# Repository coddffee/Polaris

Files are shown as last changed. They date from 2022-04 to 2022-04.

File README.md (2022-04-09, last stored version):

# `K210`工程配置

## 编译环境

### `Windows`平台

```xxx
1.配置GCC编译环境 : 下载MinGW-64并将根目录下的bin路径添加至系统环境变量，使用"gcc --version"命令检查是否配置成功
2.配置RISCV编译工具链 : 在K210官网下载kendryte-toolchain-win-amd64工具链并将根目录下的bin路径添加至系统环境变量，
  使用"riscv64-unknown-elf-gcc --version"命令检查是否配置成功
3.配置CMake : 下载CMake并将根目录下的bin路径添加至系统环境变量，使用"cmake --version"检查是否配置成功
```

### `Linux`平台

```xxx
TODO
```

## 工程结构

### K210-Standalone-SDK文件结构

```xxx
K210-Standalone-SDK
|---cmake
    |---CMakeLists.txt
    |---common.cmake
    |---compile-flags.cmake
    |---dump-config.cmake
    |---executable.cmake
    |---fix-9985.cmake
    |---macros.cmake
    |---macros.internal.cmake
    |---toolchain.cmake
|---lib
    |---bsp
        |---include
            |---xxx.h
        |---crt.S
        |---xxx.c
    |---drivers
        |---include
            |---xxx.h
        |---xxx.c
    |---utils
        |---include 
            |---syslog.h
    |---CMakeLists.txt
|---lds(链接脚本)
    |---kendryte.ld
```

&emsp;&emsp;使用`CMakeLists.txt`配置工程时需要直接使用`SDK`下`cmake`中的`CMakeLists.txt`,`common.cmake`和`executable.cmake`，`cmake`文件夹中的文件作用分别为：

```xxx
1.CMakeLists.txt : 配置SDK工程结构，生成名为kendryte的静态链接库
2.macros.cmake&macros.internal.cmake : 定义一些工具函数和变量
3.toolchain.cmake : 用于配置编译工具链，要求提前定义WIN32变量用于指定编译平台，
  要求提前定义TOOLCHAIN变量用于指定编译工具链所在目录(工具链根目录下的bin路径)
4.compile-flags.cmake : 存放编译和链接选项
5.dump-config.cmake : 用于打印一些必要变量的值辅助检查工程的配置
6.fix-9985.cmake : 进行某些字符串的替换
7.common.cmake : 调用toolchain.cmake,compile-flags.cmake和fix-9985.cmake,主要用于配置编译工具链，设置编译链接选项，
  此文件应该在所有生成目标文件的指令之前调用，可在项目级CMakeLists.txt的靠前部分调用
8.executable.cmake : 用于生成可执行文件，此文件要求提前定义变量SOURCE_FILES用于存储生成可执行文件的源文件，
  并指定可执行文件的文件名为${PROJECT_NAME},此文件应该在工程的链接操作之前调用，另外此文件还进行了可执行文件格式转换操作，
  将GCC编译器编译得到的ELF格式文件转换为二进制格式文件
```

## 工程配置

### 工程级`CMakeLists.txt`编写

```cmake
# 开启交叉编译
set(CMAKE_SYSTEM_NAME Generic)
cmake_minimum_required(VERSION 3.0)
project(Polaris LANGUAGES C ASM)

# SDK配置
# 设置编译工具链路径，TOOLCHAIN是K210-SDK中定义的变量，需由使用者指定
set(TOOLCHAIN C:/DevEnv/Kendryte-Toolchain/bin)
# 指定编译平台为WIN32，WIN32是K210-SDK中定义的变量，根据此变量指定toolchain的后缀名，需由使用者指定
set(WIN32 TRUE)

add_subdirectory(${PROJECT_SOURCE_DIR}/sdk/k210/cmake)
```

### 项目编译

&emsp;&emsp;`Windows`平台：

```shell
# 在build目录下运行cmake指令，产生的Makefiles将存放于build目录下，避免污染项目结构
cd ./build
# 运行cmake指令时必须使用"-G"指定cmake生成器，否则无法进行交叉编译
# 对于Windows平台使用MinGW-GCC环境，cmake生成器为"MinGW Makefiles"
cmake -G "MinGW Makefiles" ../
# 运行make指令执行Makefiles完成编译
make
```

&emsp;&emsp;`Linux`平台：

```shell
# 在build目录下运行cmake指令，产生的Makefiles将存放于build目录下，避免污染项目结构
cd ./build
# 运行cmake指令时必须使用"-G"指定cmake生成器，否则无法进行交叉编译
# 对于Linux平台，cmake生成器为"Unix Makefiles"
cmake -G "Unix Makefiles" ../
# 运行make指令执行Makefiles完成编译
make
```

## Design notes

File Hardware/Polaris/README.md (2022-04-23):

# 硬件设计

## K210

&emsp;&emsp;[官方数据手册](https://github.com/kendryte/kendryte-doc-datasheet)

### 电源

&emsp;&emsp;K210的电源引脚：

| 电源PIN组 | 电压 | 功能 | 最大电流 |
| :---: | :---: | :---: | :---: |
| VDDIOxA(x=0~2) | 1.8V/3.3V | 为可切换电压的GPIO-GroupA/Bankx(x=0~2)供电 |  200mA |
| VDDIOxB(x=3~5) | 1.8V/3.3V | 为可切换电压的GPIO-GroupB/Bankx(x=3~5)供电 |  200mA |
| VDDIOxB(x=6~7) | 1.8V/3.3V | 为可切换电压的GPIO-GroupC/Bankx(x=6~7)供电 |  200mA |
| VDDIO18 | 1.8V | 为不可切换电压(固定为1.8V)的专用功能IO供电 |  200mA |
| VDDOTP | 1.8V | 为一次可编程存储器供电 | 50mA |
| VDD | 0.9V | 为K210核心供电 |  2000mA  |
| VSS | 0V | 数字接地 | --- |
| VDDPLL | 0.9V | 锁相环电路供电 | 15mA |
| VSSPLL | 0V | 锁相环电路接地，噪声敏感 | --- |

&emsp;&emsp;K210的48个GPIO按照电源可分为3组，分别是VDDIOxA,VDDIOxB,VDDIOxC, A,B,C三组又可分为8个Bank，分别为Bank0~Bank7,分别对应的GPIO为：

| Bank | Bank | GPIO |
| :--: | :--: | :---: |
|  0 |  A |  IO-0~IO_5  |
|  1 |  A | IO-6~IO_11  |
|  2 |  A | IO-12~IO_17 |
|  3 |  B | IO-18~IO_23 |
|  4 |  B | IO-24~IO_29 |
|  5 |  B | IO-30~IO_35 |
|  6 |  C | IO-36~IO_41 |
|  7 |  C | IO-42~IO_47 |

&emsp;&emsp;VDDIO18供电的IO均为专用IO,功能固定，分别是：

| IO | 功能 |
| :---: | :---: |
| SPIO_D0~SPIO_D7 | SPIO0专用IO |
| DVP_D0~DVP_D7 | DVP专用IO |
| F_CLK,F_CS,F_D0,F_D1,F_D2,F_D3 | SPI-FLASH专用IO |
| RESET,CLK,OSC_CLK,XTAL_IN,XTAL_OUT | 复位，有源&无源时钟输入输出 |

&emsp;&emsp;使得K210正常工作必须提供3.3V,1.8V,0.9V这三个电源，除PLL外其余电源均可直接接入VSS数字电源地，至于PLL电源可分别将VDDPLL与VSSPLL串联合适的磁珠或0ohm电阻接入数字电源0.9V和VSS.可选用三通道的电源管理芯片。

### 时钟

&emsp;&emsp;K210的时钟引脚：

| 引脚 | 功能 | 说明 |
| :---: | :---: | :---: |
| XTAL_IN(M4)  |  无源晶振输入  | 禁止灌入有源信号 |
| XTAL_OUT(M3) |  无源晶振输出  | 禁止灌入有源信号 |
| OSC_CLK(L3)  | 有源振荡器输出 | 时钟源自外部无源晶振 |
| CLK(M2) |  系统时钟输入  | 输入有源信号 |

&emsp;&emsp;可直接向CLK输入有源信号为系统提供时钟，也可接入26MHz无源晶振，再将OSC_CLK输出的信号输入CLK为系统提供时钟。具体选用SMD-3225四脚封装形式的26MHz无源晶振。

### BOOT

&emsp;&emsp;B12(IO_16)是K210的启动模式选择引脚(BOOT)，上电复位时IO_16为高则从FLASH启动，IO_16为低则进入ISP模式；ISP模式下使用H11(IO_4,UART0_RX)和H12(IO_5,UART0_TX)引脚通过UART下载程序到FLASH.复位引脚为M1(RESETN,IO-1.8V),低电平复位。<br>&emsp;&emsp;项目中将BOOT,RESET,UART_RX,UART_TX四个用于程序下载的引脚以触点形式引出，并与充电接口一同封装，ISP下载程序时由外部与触点连接的连接器拉低BOOT,RESET信号也由外部给出。另外正常模式下UART_RX与UART_TX可作为外部扩展模块的通信接口。

### FLASH

&emsp;&emsp;K210不具备片上FLASH,需要通过专用SPI3连接至外部FLASH,引脚如下：

| 引脚 | 功能  | 说明 |
| :---: | :---: | :---: |
| F_D0(J1)  |  DI | Data Input, 1.8V only |
| F_D1(G1)  |  DO | Data Output, 1.8V only |
| F_D2(H1)  |  /WP  | Write Protect Input, 1.8V only |
| F_D3(L1)  | /Hold | Hold Input, 1.8V only |
| F_CLK(K1) |  CLK  | SPI Clock, 1.8V only |
| F_CS(G2)  |  /CS  | SPI Chip Select, 1.8V only |

&emsp;&emsp;SPI-FLASH芯片必须使用1.8V芯片，可选择容量为SPI-NOR-FLASH类型的8MiB(8.192MB)/16MiB(16.384MB)/32MiB(32.768MB).通信协议使用QSPI(Queued-SPI,6wire).<br>&emsp;&emsp;SPI-FLASH具体型号选用GD25LQ128DWIGR(兆易创新)，1.8V驱动电压，128M-bit存储容量，WSON8(6mm*5mm)封装。

## 系统电源

### K210

&emsp;&emsp;必须为K210提供0.9V,1.8V和3.3V三种规格的电压，推荐使用三通道单片机专用电源管理芯片RY1303. RY1303具有三路Buck转换器，输入电压范围为2.7V-5.5V, 输出电压可调范围为0.6V-Vin. 最大连续负载电流为2A, 三通道功率总和必须小于6W. 需注意RY1303与RY1303A有所区别，RY1303的16脚为VCC, RY1303A的16脚为NC.

### 电池管理

&emsp;&emsp;使用3.7V锂聚合物电池为系统供电，电池管理电路包含电池保护电路、充电管理电路和电量计电路三部分，保护电路用于避免电池的过充、过放；充电管理电路用于为电池充电并将电池电压升压后提供系统使用，电量计用于上报电池电量百分比。

### 其他外设

## 显示屏

&emsp;&emsp;显示屏使用上海冠显TA018NHV01-1.78寸AMOLED屏幕，其分辨率为368*448(24位RGB), 显示驱动为RM69090, 可选择MIPI接口或SPI接口与之通信；触摸驱动为TMA525C, 使用I2C接口与之通信。

## 传感器

&emsp;&emsp;重力加速度传感器使用MPU6500, 其驱动电压范围为1.8V-3.3V; 通过SPI总线和中断线与K210通信；电子指南针传感器使用HMC5883L, 其驱动电压范围为2.6V-3.3V; 通过I2C总线与中断线与K210通信。

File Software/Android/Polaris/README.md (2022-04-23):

# 高德地图API使用笔记

## 获取API-Key

&emsp;&emsp;API-Key是使用高德地图API时必须使用的密钥，可在高德地图开发者控制台上通过创建一个新应用的方式获取API-Key, 一个Key只能用于一个应用的开发。创建应用之前需要在AndroidStudio中获取发布版安全码SHA1和调试版安全码SHA1及应用Package.

### 获取SHA1

```xxx
1.将JDK自带的keytool添加至环境变量(将JDK安装目录下的bin路径添加至环境变量即可)
2.在AndroidStudio下创建keystore:
  (1)依次点击Build->Generate Signed Bundle / APK
  (2)选择存储路径并输入keystore名和密码
  (3)选择keystore的应用目标(debug/release或者两者均是)
3.获取SHA1:
  (1)打开终端并切换到步骤2生成的keystore所在的目录下
  (2)输入命令"keytool -list -v -keystore xxx.jks","xxx.jks"为keystore文件名，新版AndroidStudio的keystore后缀为.jks
  (3)输入步骤2中生成keystore时设置的密码
  (4)在返回信息中可查看SHA1
```

### 获取Package

&emsp;&emsp;即App的`AndroidManifest.xml`中的根标签的package属性。

### 创建高德地图新应用

&emsp;&emsp;在高德地图开发者控制台的应用管理中创建新应用并输入SHA1和Package即可得到对应的API-Key

### 在开发中使用API-Key

&emsp;&emsp;在`AndroidManifest.xml`的`<application>`标签中添加API-Key, 如：

```xml
<application...>
    <!-- value属性赋API-Key -->
    <meta-data
        android:name="com.amap.api.v2.apikey"
        android:value="45ebf..."/>
    ...
</application...>
```

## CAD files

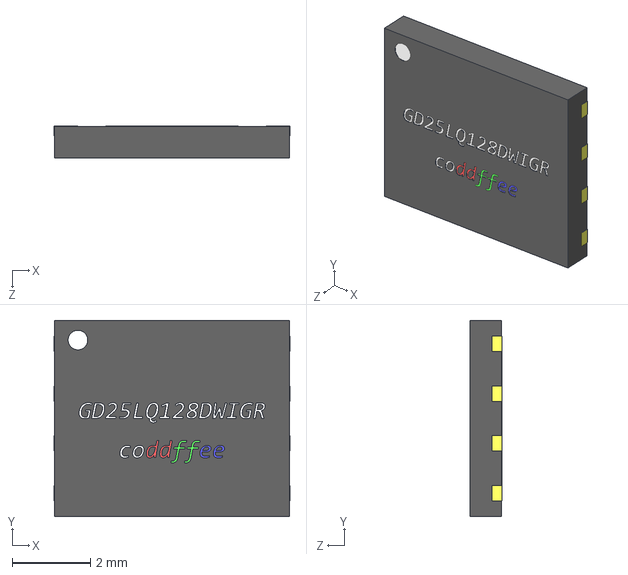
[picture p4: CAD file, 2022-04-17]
Mechanic/PCB3DLib/GD25LQ128DWIGR/GD25LQ128DWIGR.STEP
6.02 x 5.00 x 0.81 mm

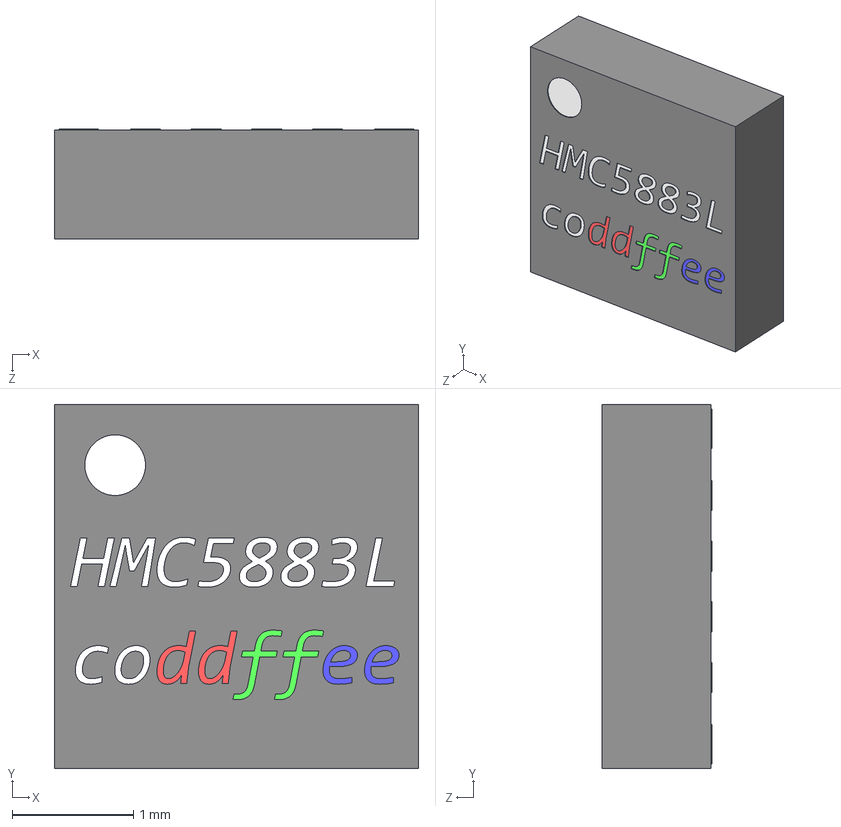
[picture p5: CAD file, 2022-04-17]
Mechanic/PCB3DLib/HMC5883L/HMC5883L.STEP
3.00 x 3.00 x 0.91 mm

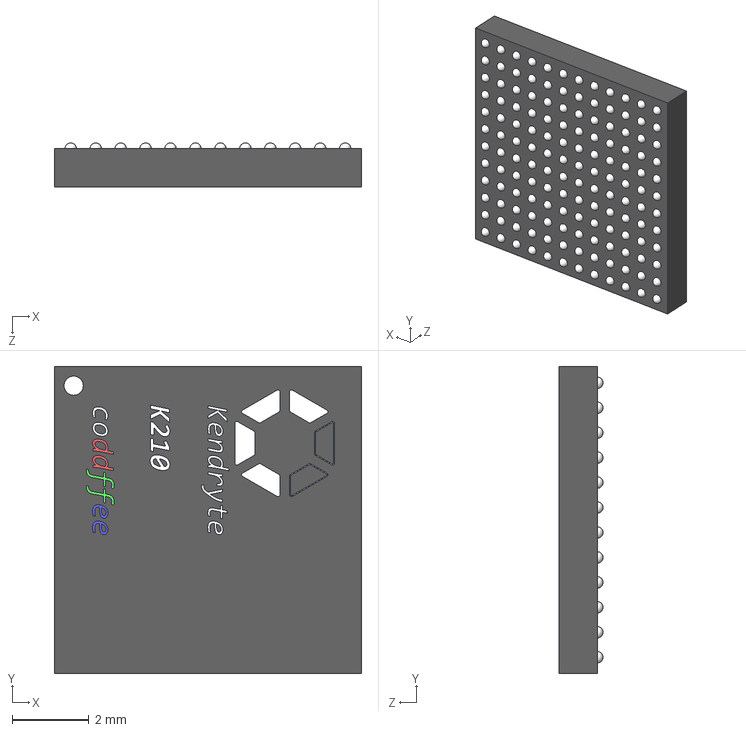
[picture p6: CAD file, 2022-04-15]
Mechanic/PCB3DLib/K210/K210.STEP
8.00 x 8.00 x 1.15 mm

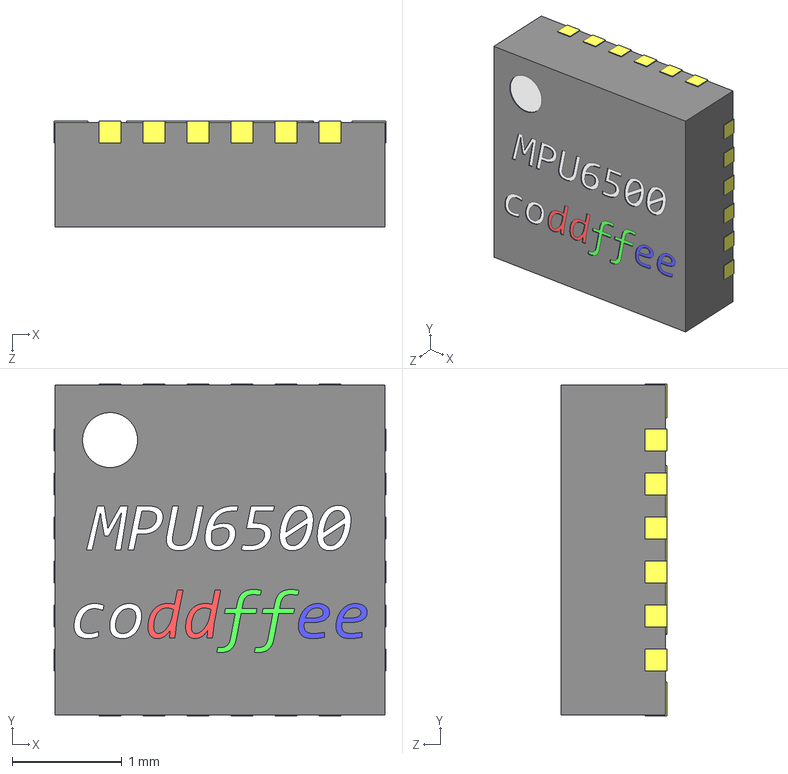
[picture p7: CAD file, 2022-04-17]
Mechanic/PCB3DLib/MPU6500/MPU6500.STEP
3.02 x 3.02 x 0.96 mm

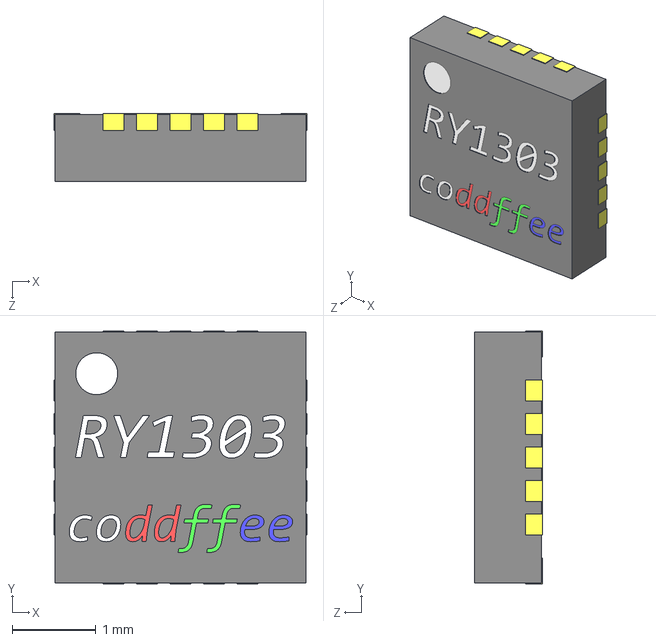
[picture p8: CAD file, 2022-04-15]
Mechanic/PCB3DLib/RY1303/RY1303.STEP
3.02 x 3.02 x 0.81 mm

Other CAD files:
Mechanic/PCB3DLib/GD25LQ128DWIGR/GD25LQ128DWIGR.SLDPRT
Mechanic/PCB3DLib/HMC5883L/HMC5883L.SLDPRT
Mechanic/PCB3DLib/K210/K210.SLDPRT
Mechanic/PCB3DLib/MPU6500/MPU6500.SLDPRT
Mechanic/PCB3DLib/RY1303/RY1303.SLDPRT

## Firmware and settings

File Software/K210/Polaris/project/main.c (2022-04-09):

#include <stdio.h>
#include <unistd.h>
#include "fpioa.h"
#include "gpio.h"
#include "sleep.h"

int main() {
    fpioa_set_function(12, FUNC_GPIO1);
    fpioa_set_function(13, FUNC_GPIO2);
    fpioa_set_function(14, FUNC_GPIO3);

    gpio_init();
    gpio_set_drive_mode(1, GPIO_DM_OUTPUT);
    gpio_set_drive_mode(2, GPIO_DM_OUTPUT);
    gpio_set_drive_mode(3, GPIO_DM_OUTPUT);
    gpio_pin_value_t value = GPIO_PV_HIGH;
    gpio_set_pin(1, value);
    gpio_set_pin(2, value);
    gpio_set_pin(3, value);
    while (1) {
        msleep(100);
        gpio_set_pin(1, value = !value);
        gpio_set_pin(2, value = !value);
        gpio_set_pin(3, value = !value);
    }
    return 0;
}
